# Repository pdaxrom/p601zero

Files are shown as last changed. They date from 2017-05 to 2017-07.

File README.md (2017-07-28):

## Pyldin-601 compatible retrocomputer.

[History](docs/HISTORY.md)

### Overview hardware version 1.2:

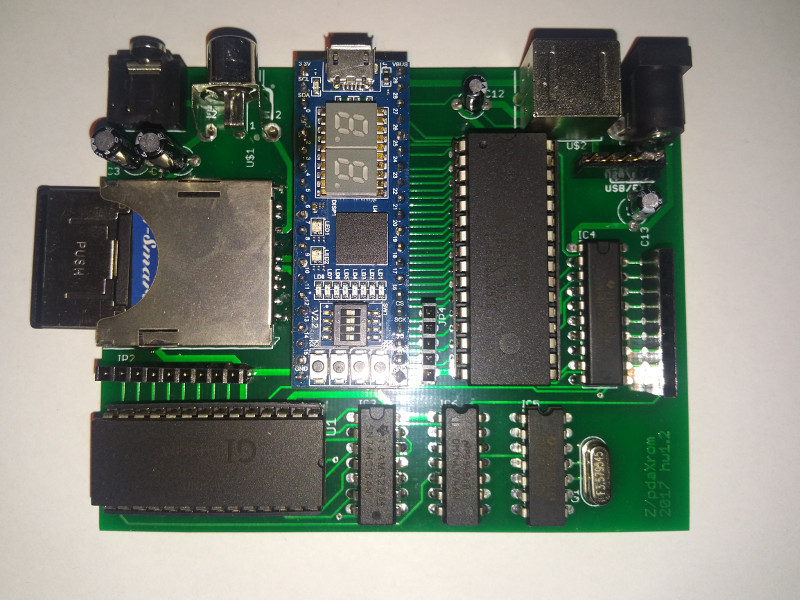
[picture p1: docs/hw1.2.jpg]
board version 1.2


 Function | Description 
----|----
CPU | [System 11 - VHDL 68HC11](http://members.optusnet.com.au/jekent/system11/)
FPGA| [Lattice MachXO2-4000HC module](http://www.stepfpga.com)
RAM | Builtin FPGA 4KB and/or external static ram 128KB
ROM | Builtin FPGA BOOTROM 2KB
Keyboard | PS/2
Serial port | UART (via keyboard connector)
Video | TV (b/w)
Audio | AY-3-8912
Storage | MMC/SD
Other | Onboard SPI and CS ports, 8 bit parallel port (limited to output only)

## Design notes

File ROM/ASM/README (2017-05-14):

Run compiled code on the board

1) Load code to the board
    ../bootloader /dev/ttyUSB0 load DEMO1.CMD 100

2) Run loaded code:
    ../bootloader /dev/ttyUSB0 go 100

For code that use UART, run terminal in non locking mode:
    picocom -l -b 115200 /dev/ttyUSB0

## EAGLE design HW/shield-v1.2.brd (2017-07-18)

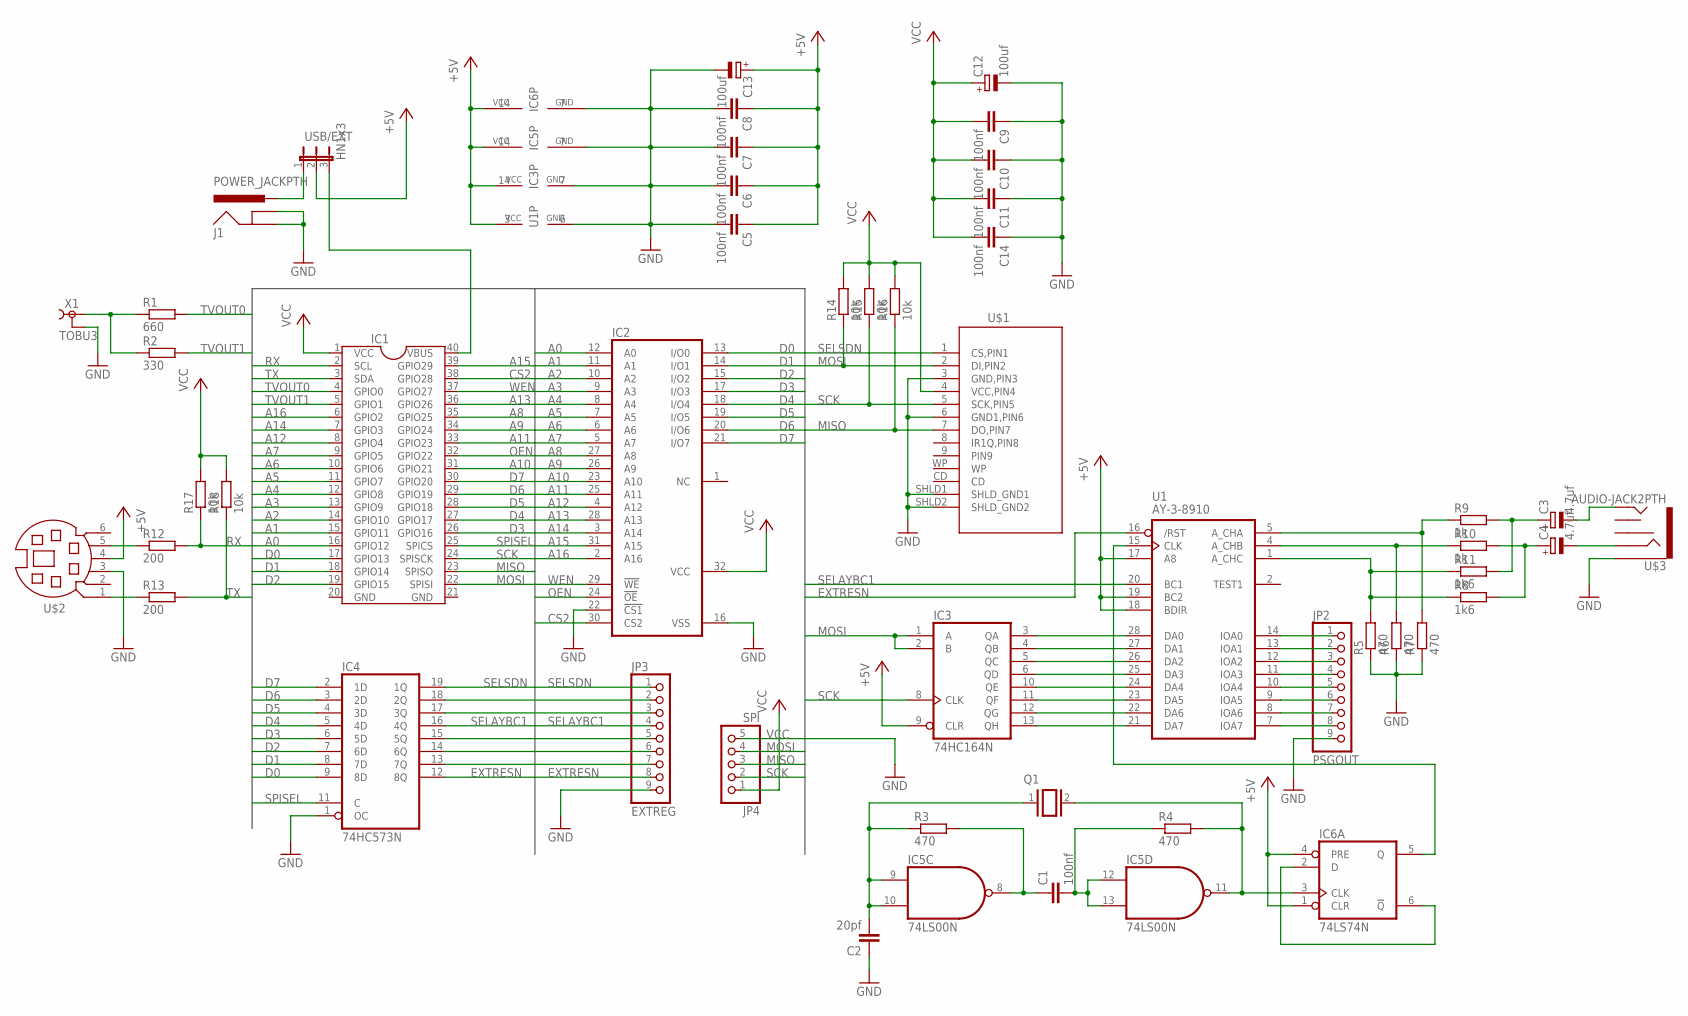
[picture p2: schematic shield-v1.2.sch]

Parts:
C1, C5, C6, C7, C8, C9, C10, C11, C14: 100nf; 1206
C2: 20pf; 1206
C3, C4: 4.7uf; E5-5
C12, C13: 100uf; E5-5
IC1: STEPFPGA; DIL40
IC2: 628128P; DIL32
IC3: 74HC164N; DIL14
IC4: 74HC573N; DIL20
IC5: 74LS00N; DIL14
IC6: 74LS74N; DIL14
J1: POWER_JACKPTH; POWER_JACK_PTH
JP2: PSGOUT; 1X09
JP3: EXTREG; 1X09
JP4: SPI; 1X05
Q1: XTAL/S; QS
R1: 660; R1206
R2: 330; R1206
R3, R4, R5, R6, R7: 470; R1206
R8, R11: 1k6; R1206
R9, R10: 1k; R1206
R12, R13: 200; R1206
R14, R15, R16, R17, R18: 10k; R1206
U1: AY-3-8910; DIL28-6
U$1: FCI_SD_SOCKET; SD-MMC_SOCKET-PP
U$2: MD06SS; MDIN06SS
U$3: AUDIO-JACK2PTH; AUDIO-JACK
USB/EXT: HN1x3; JP2
X1: TOBU3

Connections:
+5V: C5.1, C6.1, C7.1, C8.1, C13.+, IC3.9 (CLR), IC3.14 (VCC), IC5.14 (VCC), IC6.1 (CLR), IC6.4 (PRE), IC6.14 (VCC), U1.3 (VCC), U1.17 (A8), U1.18 (BDIR), U1.19 (BC2), U$2.4, USB/EXT.2
A0: IC1.16 (GPIO12), IC2.12 (A0)
A1: IC1.15 (GPIO11), IC2.11 (A1)
A2: IC1.14 (GPIO10), IC2.10 (A2)
A3: IC1.13 (GPIO9), IC2.9 (A3)
A4: IC1.12 (GPIO8), IC2.8 (A4)
A5: IC1.11 (GPIO7), IC2.7 (A5)
A6: IC1.10 (GPIO6), IC2.6 (A6)
A7: IC1.9 (GPIO5), IC2.5 (A7)
A8: IC1.35 (GPIO25), IC2.27 (A8)
A9: IC1.34 (GPIO24), IC2.26 (A9)
A10: IC1.31 (GPIO21), IC2.23 (A10)
A11: IC1.33 (GPIO23), IC2.25 (A11)
A12: IC1.8 (GPIO4), IC2.4 (A12)
A13: IC1.36 (GPIO26), IC2.28 (A13)
A14: IC1.7 (GPIO3), IC2.3 (A14)
A15: IC1.39 (GPIO29), IC2.31 (A15)
A16: IC1.6 (GPIO2), IC2.2 (A16)
CS2: IC1.38 (GPIO28), IC2.30 (CS2)
D0: IC1.17 (GPIO13), IC2.13 (I/O0), IC4.9 (8D)
D1: IC1.18 (GPIO14), IC2.14 (I/O1), IC4.8 (7D)
D2: IC1.19 (GPIO15), IC2.15 (I/O2), IC4.7 (6D)
D3: IC1.26 (GPIO16), IC2.17 (I/O3), IC4.6 (5D)
D4: IC1.27 (GPIO17), IC2.18 (I/O4), IC4.5 (4D)
D5: IC1.28 (GPIO18), IC2.19 (I/O5), IC4.4 (3D)
D6: IC1.29 (GPIO19), IC2.20 (I/O6), IC4.3 (2D)
D7: IC1.30 (GPIO20), IC2.21 (I/O7), IC4.2 (1D)
EXTRESN: IC4.12 (8Q), JP3.8, U1.16 (/RST)
GND: C2.1, C5.2, C6.2, C7.2, C8.2, C9.1, C10.1, C11.1, C12.-, C13.-, C14.1, IC1.20 (GND), IC1.21 (GND), IC2.16 (VSS), IC2.22 (!CS1), IC3.7 (GND), IC4.1 (OC), IC4.10 (GND), IC5.7 (GND), IC6.7 (GND), J1.GND, J1.GNDBREAK, JP2.9, JP3.9, JP4.5, R5.1, R6.1, R7.1, U1.6 (GND), U$1.3 (GND,PIN3), U$1.6 (GND1,PIN6), U$1.SHLD1 (SHLD_GND1), U$1.SHLD2 (SHLD_GND2), U$2.3, U$3.SLEEVE, X1.2, X1.2@1 (2), X1.2@2 (2)
MISO: IC1.23 (SPISO), JP4.3, R16.1, U$1.7 (DO,PIN7)
MOSI: IC1.22 (SPISI), IC3.1 (A), IC3.2 (B), JP4.4, R14.1, U$1.2 (DI,PIN2)
unnamed: R1.1, R2.1, X1.1
unnamed: IC3.3 (QA), U1.28 (DA0)
unnamed: IC3.4 (QB), U1.27 (DA1)
unnamed: IC3.5 (QC), U1.26 (DA2)
unnamed: IC3.6 (QD), U1.25 (DA3)
unnamed: IC3.10 (QE), U1.24 (DA4)
unnamed: IC3.11 (QF), U1.23 (DA5)
unnamed: IC3.12 (QG), U1.22 (DA6)
unnamed: IC3.13 (QH), U1.21 (DA7)
unnamed: R5.2, R8.1, R11.1, U1.1 (A_CHC)
unnamed: C1.1, IC5.8 (O), R3.2
unnamed: C1.2, IC5.12 (I0), IC5.13 (I1), R4.1
unnamed: C2.2, IC5.9 (I0), IC5.10 (I1), Q1.1, R3.1
unnamed: IC5.11 (O), IC6.3 (CLK), Q1.2, R4.2
unnamed: R6.2, R10.1, U1.4 (A_CHB)
unnamed: IC6.2 (D), IC6.6 (!Q)
unnamed: IC6.5 (Q), U1.15 (CLK)
unnamed: R7.2, R9.1, U1.5 (A_CHA)
unnamed: C4.+, R8.2, R10.2
unnamed: C3.+, R9.2, R11.2
unnamed: C3.-, U$3.TIP
unnamed: C4.-, U$3.RING
unnamed: R12.1, U$2.5
unnamed: R13.1, U$2.1
unnamed: JP2.1, U1.14 (IOA0)
unnamed: JP2.2, U1.13 (IOA1)
unnamed: JP2.3, U1.12 (IOA2)
unnamed: JP2.4, U1.11 (IOA3)
unnamed: JP2.5, U1.10 (IOA4)
unnamed: JP2.6, U1.9 (IOA5)
unnamed: JP2.7, U1.8 (IOA6)
unnamed: JP2.8, U1.7 (IOA7)
unnamed: IC4.18 (2Q), JP3.2
unnamed: IC4.17 (3Q), JP3.3
unnamed: IC4.15 (5Q), JP3.5
unnamed: IC4.14 (6Q), JP3.6
unnamed: IC4.13 (7Q), JP3.7
unnamed: J1.PWR, USB/EXT.1
unnamed: IC1.40 (VBUS), USB/EXT.3
OEN: IC1.32 (GPIO22), IC2.24 (!OE)
RX: IC1.2 (SCL), R12.2, R17.1
SCK: IC1.24 (SPISCK), IC3.8 (CLK), JP4.2, R15.1, U$1.5 (SCK,PIN5)
SELAYBC1: IC4.16 (4Q), JP3.4, U1.20 (BC1)
SELSDN: IC4.19 (1Q), JP3.1, U$1.1 (CS,PIN1)
SPISEL: IC1.25 (SPICS), IC4.11 (C)
TVOUT0: IC1.4 (GPIO0), R1.2
TVOUT1: IC1.5 (GPIO1), R2.2
TX: IC1.3 (SDA), R13.2, R18.1
VCC: C9.2, C10.2, C11.2, C12.+, C14.2, IC1.1 (VCC), IC2.32 (VCC), IC4.20 (VCC), JP4.1, R14.2, R15.2, R16.2, R17.2, R18.2, U$1.4 (VCC,PIN4)
WEN: IC1.37 (GPIO27), IC2.29 (!WE)

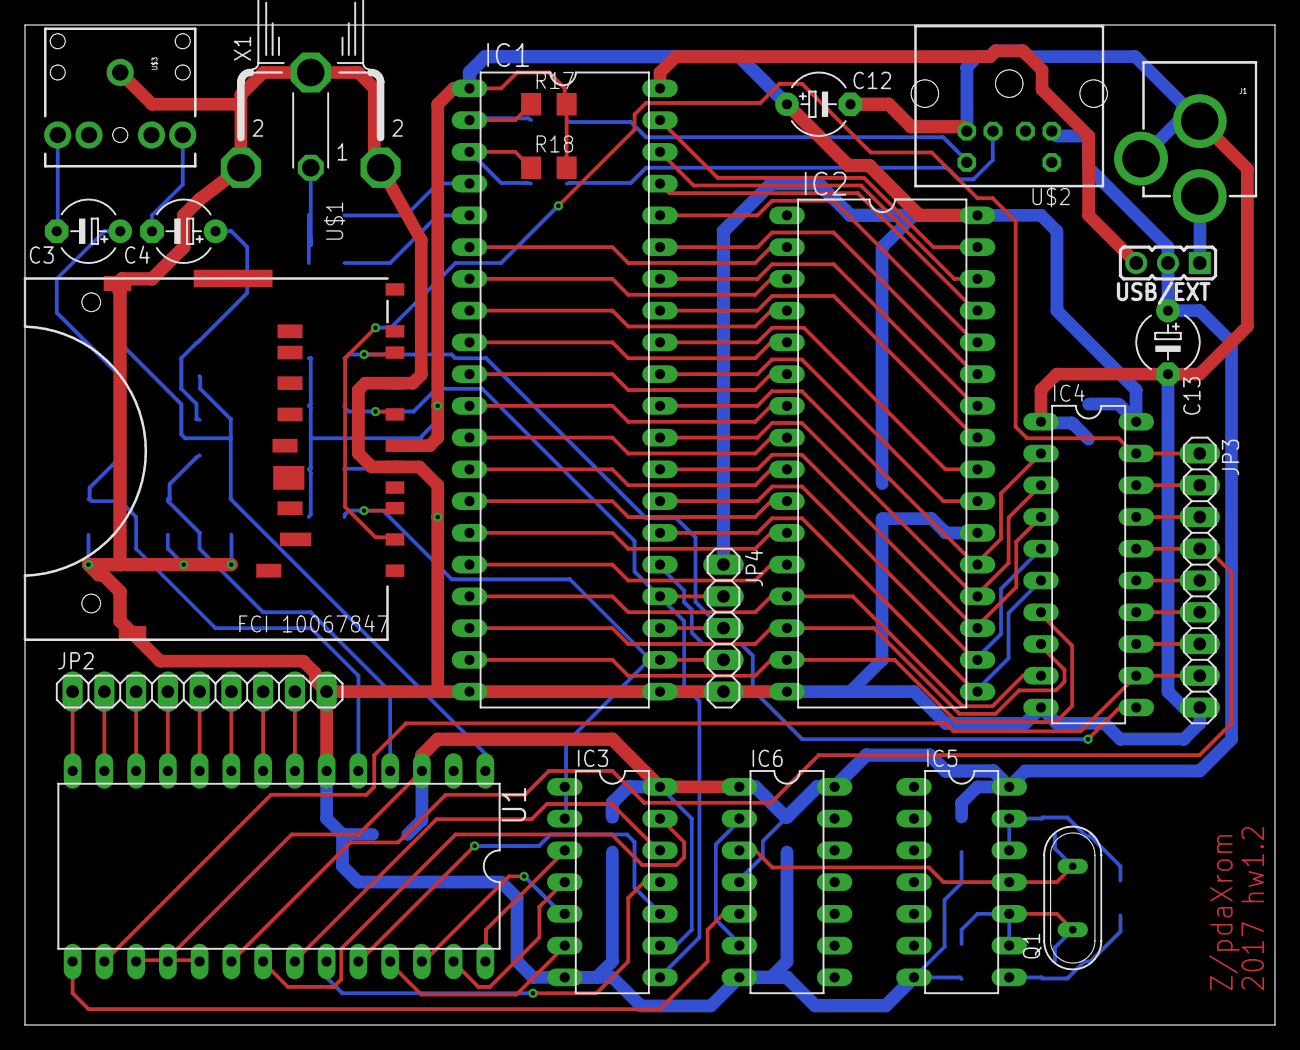
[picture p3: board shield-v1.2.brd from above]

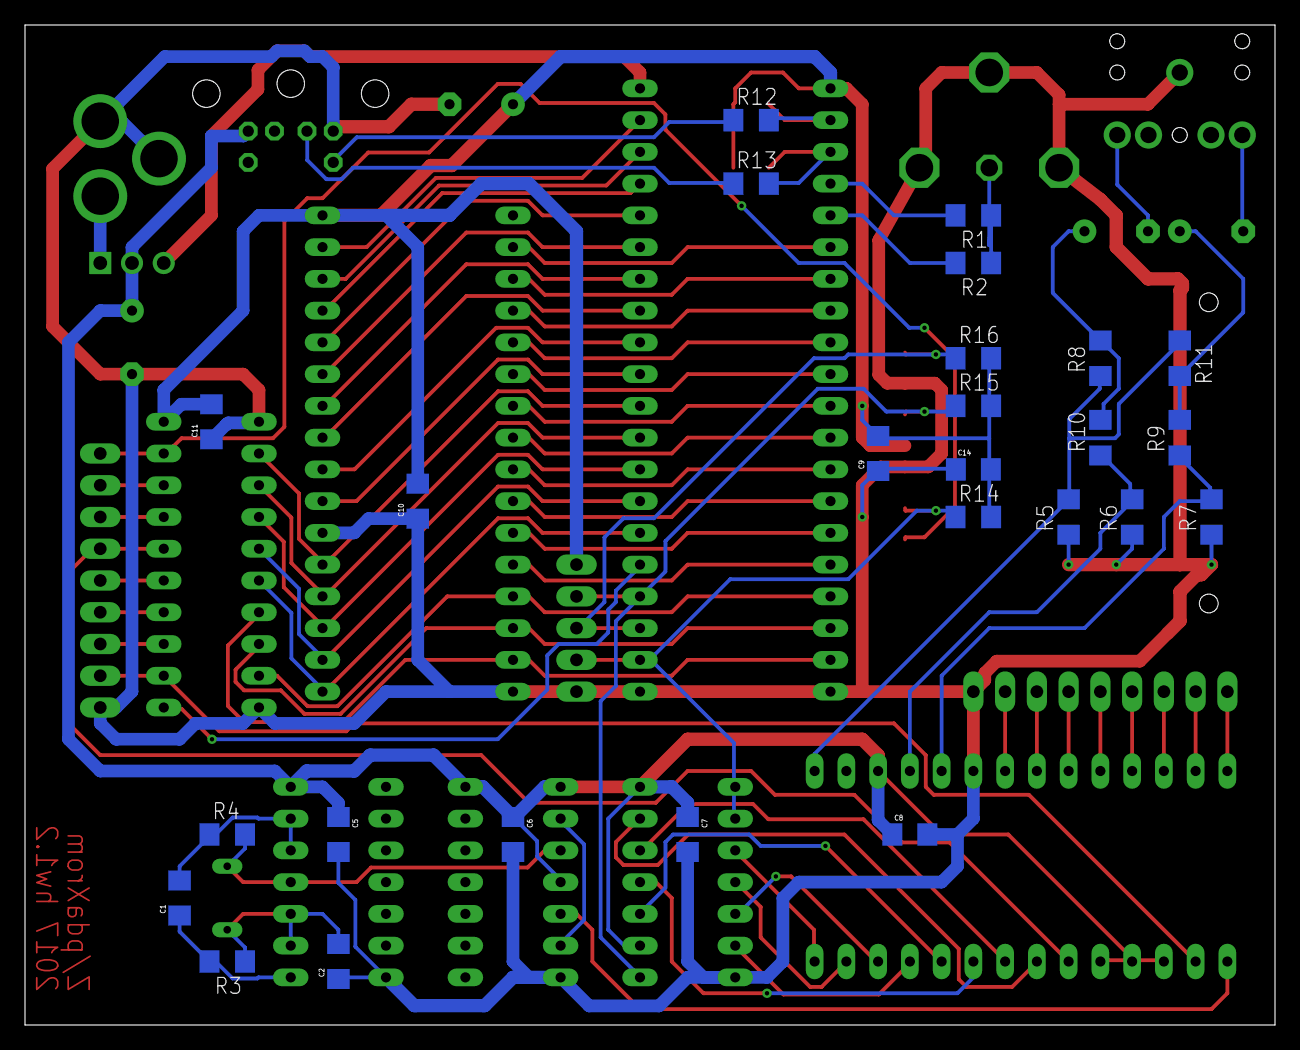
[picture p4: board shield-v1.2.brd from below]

Board: 2 copper layers, 100.0 x 80.0 mm, 49 parts (26 on the bottom side), 81 nets.

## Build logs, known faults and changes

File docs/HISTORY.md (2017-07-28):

# History of pdaXrom

year | description
-----|-----
2003-2007 | arm linux distro for Sharp Zaurus PDA.
2007-2014 | renamed as pdaXrom-ng, powerpc bootloader and distro for Sony Playstation 3, mips32/64 distro for Lemote Yeeloong 8101B, arm distro for RAME/PCIO terminal hardware
2012-2017 | cctools - development packages for Android
2017 | Z/pdaXrom - FPGA based computer

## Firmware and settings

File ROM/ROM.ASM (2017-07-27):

;
; BOOTROM for Z/pdaXrom
; (c) sashz <sashz@pdaXrom.org>, 2017
;

	include DEVMAP.INC

;
; BootROM variables and functions
;

	include BOOTROM.INC

	include BOOTMEM.INC

	org	BOOTROM_BASE

reset	sei

	ldaa	RAMPAGE_CTL
	oraa	#BRAM_DISABLE
	staa	RAMPAGE_CTL

; SRAM chip initialization
	ldaa	#0
sramini	ldx	#$A55A
	stx	$0
	ldx	$0
	cpx	#$A55A
	bne	sramin1
	ldab	IO_SWKEYS
	bitb	#1
	beq	sramok
	bra	onbrom
sramin1	inca
	bne	sramini

onbrom	ldab	RAMPAGE_CTL
	andb	#($FF^BRAM_DISABLE)
	stab	RAMPAGE_CTL
	ldab	#$1C
	stab	IO_L7HI
sramok	staa	$2
	staa	IO_L8BIT

; setup stubs
	ldx	#0
	stx	VECIRQP
	stx	VECNMIP

	ldx	#vstub_irq
	stx	VECIRQ
	ldx	#vstub_nmi
	stx	VECNMI
	ldx	#swihndl
	stx	VECSWI

; setup syscalls

	ldx	#BROM_SWIPAG
clrswipag clr	0,x
	inx
	cpx	#BROM_SWIPAG+$280
	bne	clrswipag

	lds	#romvecbeg
	des
	ldx	#BROM_SWIVEC+$C0*2
copyswiv pula
	staa	0,x
	inx
	cpx	#BROM_SWIVEC+$C0*2+(romvecend-romvecbeg)
	bne	copyswiv

	ldaa	IO_SWKEYS
	bita	#$80
	bne	setuart
	ldaa	#PS2_KEN
	bra	setkbd
setuart	clra
setkbd	staa	PS2_CONFIG

warmres	lds	#BROM_STACK

; reset spi/EXT devices
	jsr	spi_reset

; init putchar queue for control sequences
	clr	QUEUELEN
	ldx	#QUEUEBUF
	stx	QUEUEPTR

	ldaa	#$80
	ldx	#FBTEXT
	jsr	setvideomode

; setup prescaler: 24MHz / (Baud * 8)
	ldx	#26
	stx	UART_PRESCALER

; disable UART interrupts (clear UART_TIE and UART_RIE)
	clra
	staa	UART_CONFIG

	ldx	#pylogo
	jsr	putstr

	ldaa	RAMPAGE_CTL
	bita	#BRAM_DISABLE
	beq	bramen
	ldx	#txt_extram
	bra	ramtxt
bramen	ldx	#txt_bram
ramtxt	jsr	putstr

	ldaa	PS2_CONFIG
	bita	#PS2_KEN
	beq	showuart
	ldx	#txt_kbd
	bra	showkbd
showuart ldx	#txt_uart
showkbd	jsr	putstr

;
; Trying to boot from SD
;
	jsr	sd_init
	tsta
	bne	no_sd_boot
	ldx	#txt_sd
	jsr	putstr

	ldx	#boot_sec
	jsr	sd_read
	tsta
	bne	no_sd_boot
	ldx	$2FE
	cpx	#$55AA
	bne	no_sd_boot
	jsr	$13E

no_sd_boot ldx	#txt_nl
	jsr	putstr

loop	bsr	uart_in
	cmpa	#'L'
	beq	cmd_load
	cmpa	#'S'
	beq	cmd_save
	cmpa	#'G'
	beq	cmd_go
	ldaa	#'E'
	bsr	uart_out
	bra	loop

cmd_load
	bsr	get_block_addr
cmd_lo1	bsr	uart_in
	staa	0,x
	inx
	cpx	END_ADDR
	bne	cmd_lo1
cmd_oka	ldaa	#'O'
	bsr	uart_out
	bra	loop

cmd_save
	bsr	get_block_addr
cmd_sa1	ldaa	0,x
	bsr	uart_out
	inx
	cpx	END_ADDR
	bne	cmd_sa1
	bra	cmd_oka

cmd_go
	bsr	get_word
	jsr	0,x
	jmp	warmres

get_block_addr proc
	bsr	get_word
	pshx
	bsr	get_word
	stx	END_ADDR
	pulx
	rts
	endp

;; UART IN/OUT

uart_in proc
	ldaa	UART_STATUS
	bita	#UART_RRD
	beq	uart_in
	ldaa	UART_DATA
	rts
	endp

uart_out proc
	pshb
loop	ldab	UART_STATUS
	bitb	#UART_TRD
	beq	loop
	staa	UART_DATA
	pulb
	rts
	endp

get_word proc
	bsr	uart_in
	tab
	bsr	uart_in
	psha
	pshb
	pulx
	rts
	endp

;;;;;;;;;;;;;;;;;;;;;;;;;;;;;;;;;;;;;;;;;;;;;;;;;;;;;;;;;;;;;;;;;;;;;;;;;;;;;;;;
;;;;;;;;;;;;;;;;;;;;;;;;;;;;;;;;;;;;;;;;;;;;;;;;;;;;;;;;;;;;;;;;;;;;;;;;;;;;;;;;
;;;;;;;;;;;;;;;;;;;;;;;;;;;;;;;;;;;;;;;;;;;;;;;;;;;;;;;;;;;;;;;;;;;;;;;;;;;;;;;;
; Get PS/2 keyboard code
; Return A - code
;
;getscancode proc
;loop	ldaa	PS2_STATUS
;	bita	#PS2_KRD
;	beq	loop
;	ldaa	PS2_DATA
;	rts
;	endp

;;;;;;;;;;;;;;;;;;;;;;;;;;;;;;;;;;;;;;;;;;;;;;;;;;;;;;;;;;;;;;;;;;;;;;;;;;;;;;;;
;;;;;;;;;;;;;;;;;;;;;;;;;;;;;;;;;;;;;;;;;;;;;;;;;;;;;;;;;;;;;;;;;;;;;;;;;;;;;;;;
;;;;;;;;;;;;;;;;;;;;;;;;;;;;;;;;;;;;;;;;;;;;;;;;;;;;;;;;;;;;;;;;;;;;;;;;;;;;;;;;
; Set video mode
; A = $00 - text, $03 - graphics,
; X = Video address
;

setvideomode proc
	pshx
	pshb
	psha
	stx	SCRADDR
	stab	SCRATTR
	tab
	anda	#$7F
	staa	SCRMODE
	ldx	txtmode
	stx	SCRSZX
	ldx	txtmode+2
	stx	SCRXADJ
	ldx	txtmode+4
	stx	SCRMASK
	cmpa	#0
	bne	mode3
	inc	SCRSZY		; 27 text rows
	inc	SCRSZY		;
	bitb	#$80
	beq	next
	ldaa	SCRSZY
	bra	clrs
mode3	cmpa	#3
	bne	exit
	ldaa	#VPU_GRF
	staa	SCRBITS
	bitb	#$80
	beq	next
	ldaa	SCRSZY
	lsla
	lsla
	lsla
clrs	jsr	clrscry
	clr	CURX
	clr	CURY
next	ldx	#SCRADDR
	bsr	vpuconfig
	ldaa	CURX
	ldaa	CURY
	bsr	setcursor
exit	pula
	pulb
	pulx
	rts

txtmode	db	40, 25, 11, 60, $FF^VPU_GRF, 0
	endp

; Configure VPU
; X = ptr
;
; ptr dw vaddr  ; 0
;     db width  ; 2
;     db height ; 3
;     db hadj   ; 4
;     db vadj   ; 5
;     db mask   ; 6
;     db bits   ; 7
;

vpuconfig proc
	pshb
	psha

; Set framebuffer address
	ldd	0,x
	std	VPU_VADDR

; Set start line
	clra
	ldab	5,x
	std	VPU_VSTART

; Set end line
	clra
	ldab	3,x
	lsld
	lsld
	lsld
	addd	VPU_VSTART
	std	VPU_VEND

; Framebuffer horisontal position
	ldaa	4,x
	staa	VPU_HSTART

; Start dma engine
	ldaa	2,x
	staa	VPU_HSIZE

; Set bits
	ldaa	#VPU_GRF
	anda	6,x
	oraa	7,x
	staa	VPU_CFG

	pula
	pulb
	rts
	endp

; Get video mode
; Return
; X - address
; A - mode
; B - attributes

getvideomode proc
	ldaa	SCRMODE
	ldab	SCRATTR
	ldx	SCRADDR
	rts
	endp

;;;;;;;;;;;;;;;;;;;;;;;;;;;;;;;;;;;;;;;;;;;;;;;;;;;;;;;;;;;;;;;;;;;;;;;;;;;;;;;;
;;;;;;;;;;;;;;;;;;;;;;;;;;;;;;;;;;;;;;;;;;;;;;;;;;;;;;;;;;;;;;;;;;;;;;;;;;;;;;;;
;;;;;;;;;;;;;;;;;;;;;;;;;;;;;;;;;;;;;;;;;;;;;;;;;;;;;;;;;;;;;;;;;;;;;;;;;;;;;;;;
; Set VPU cursor
; A - column
; B - row
;

vpucursor proc
	pshx
	pshb
	psha
	adda	#11
	inca
	staa	VPU_CPOS
	clra
	lsld
	lsld
	lsld
	ldx	#60
	pshx
	tsx
	addd	0,x
	pulx
	std	VPU_CSTART
	addd	#7
	std	VPU_CEND

	ldaa	VPU_CFG
	oraa	#VPU_CEN
	oraa	#VPU_CIN
;	anda	#($FF ^ VPU_CIN)
	staa	VPU_CFG

	pula
	pulb
	pulx
	rts
	endp

setcursor proc
	cmpa	SCRSZX
	bcc	exit
	cmpb	SCRSZY
	bcc	exit
	pshb
	psha
	staa	CURX
	stab	CURY
	bsr	vpucursor
	ldaa	SCRSZX
	mul
	std	CURPTR
	clra
	ldab	CURX
	addd	CURPTR
	addd	SCRADDR
	std	CURPTR
	pula
	pulb
exit	rts
	endp

getcursor proc
	ldaa	CURX
	ldab	CURY
	ldx	CURPTR
	rts
	endp

putchar	proc
	pshx
	pshb
	psha
	ldab	PS2_CONFIG
	bitb	#PS2_KEN
	bne	nouart
	jsr	uart_out

nouart	ldab	SCRMODE
	andb	#$03
	bne	return1		; graf mode not supported

	tst	QUEUELEN
	beq	putch0
queue1	ldx	QUEUEPTR
	staa	0,x
	inx
	stx	QUEUEPTR
	dec	QUEUELEN
	bne	return1
	ldx	#QUEUEBUF
	stx	QUEUEPTR
	ldaa	0,x
	cmpa	#$1E
	bne	queue1b
	ldaa	1,x
	suba	#$20
	ldab	2,x
	subb	#$20
	bsr	setcursor
	bra	return1
queue1b	cmpa	#$1B
	bne	return1
	ldaa	1,x
	bra	putnorm

return1	pula
	pulb
	pulx
	rts

putch0	cmpa	#$1B
	bne	putc1e
	ldab	#2
queueup	stab	QUEUELEN
	bra	queue1
putc1e	cmpa	#$1E
	bne	putc08
	ldab	#3
	bra	queueup
putc08	cmpa	#$08
	bne	putc09
	ldaa	CURX
	deca
	ldab	CURY
	bra	setcur
putc09	cmpa	#$09
	bne	putc0a
	ldaa	CURX
	adda	#8
	anda	#%11111000
	ldab	CURY
	bra	setcur
putc0a	cmpa	#$0A
	bne	putch0c
	ldaa	CURX
	ldab	CURY
	incb
	cmpb	SCRSZY
	bne	setcur
	bsr	scroll
	bra	return1
putch0c	cmpa	#$0C
	bne	putch0d
	bsr	clrscr
	clra
	clrb
	bra	setcur
putch0d	cmpa	#$0D
	bne	putch18
	clra
	ldab	CURY
	bra	setcur
putch18	cmpa	#$18
	bne	putch7f
	bsr	clr2eol
	bra	return1
putch7f	cmpa	#$7F
	bne	putnorm
	ldaa	CURX
	beq	return1
	deca
	ldx	CURPTR
	dex
	clr	0,x
	ldab	CURY
	bra	setcur
putnorm	ldx	CURPTR
	staa	0,x
	ldaa	CURX
	ldab	CURY
	inca
setcur	jsr	setcursor
	jmp	return1
	endp

clrscr	proc
	global	clrscry, clr2eol
	ldaa	SCRSZY
clrscry	ldab	SCRSZX
	mul
	ldx	SCRADDR
clrs1	clr	0,x
	inx
	subd	#1
	bne	clrs1
	rts

clr2eol	ldx	CURPTR
	ldaa	SCRSZY
	suba	CURX
eoloop	clr	0,x
	inx
	deca
	bne	eoloop
	rts
	endp
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

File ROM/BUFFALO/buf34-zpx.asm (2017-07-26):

*                  BUFFALO
* "Bit User's Fast Friendly Aid to Logical Operation"
*
* Rev 2.0 - 4/23/85 - added disassembler.
*                   - variables now PTRn and TMPn.
* Rev 2.1 - 4/29/85 - added byte erase to chgbyt routine.
* Rev 2.2 - 5/16/85 - added hooks for evb board - acia
*                     drivers, init and host routines.
*           7/8/85  - fixed dump wraparound problem.
*           7/10/85 - added evm board commands.
*                   - added fill instruction.
*           7/18/85 - added jump to EEPROM.
* Rev 2.3 - 8/22/85 - call targco to disconnect sci from host
*                     in reset routine for evb board.
*           10/3/85 - modified load for download through terminal.
* Rev 2.4 - 7/1/86  - Changed DFLOP address to fix conflicts with
*                     EEPROM.  (was at A000)
* Rev 2.5 - 9/8/86  - Modified to provide additional protection from
*                     program run-away on power down.  Also fixed bugs
*                     in MM and MOVE.  Changed to 1 stop bit from 2.
* Rev 2.6 - 9/25/86 - Modified boot routine for variable length download
*                     for use with 'HC11E8.
* Rev 3.0   1/15/87 - EEPROM programming routines consolidated into WRITE.
*                     Fill, Assem, and breakpoints will now do EEPROM.
*                   - Added compare a to $0D to WSKIP routine.
*           2/11/87 - Set up load to detect receiver error.
* Rev 3.2   7/7/87  - Add disassembly to trace.
*                   - Add entries to jump table.
*           9/20/87 - Rewrote trace to use XIRQ, added STOPAT Command
*           11/24/87- Write block protect reg for 'E9 version
*                   - Modified variable length download for use
*                       with 'E9 bootloader (XBOOT command)
* Rev 3.3   3/17/88 - Set I bit to block interrupts on Warm Start and 
*                       return from CALL command.
*                   - Added EEMOD Command.
*                   - Rearranged source so that HELP command overlaps
*                       EEPROM in test mode.
*           3/24/88 - Added '+', '-', '=', '.' to MEM and ASM commands.
*                   - Added check for 16 byte boundary to MEM 
*                       space sub-command.
*                   - LOAD command now puts dummy (~) command into
*                       inbuff so that any stray cr's won`t hang.
* Rev 3.4   8/15/88 - Changed WRITE subroutine so that config register 
*                       gets byte erased before programmed.  The original
*                       value of config is used for EEBYTE so that config
*                       RAM value doesn't get changed in test mode.
*           8/17/88 - Fixed MOVE command so that it doesn't hang when move
*                       is done to a ROM location.
*                   - Added OFFSET command for download offset capability.
*
****************************************************
*    Although the information contained herein,    *
*    as well as any information provided relative  *
*    thereto, has been carefully reviewed and is   *
*    believed accurate, Motorola assumes no        *
*    liability arising out of its application or   *
*    use, neither does it convey any license under *
*    its patent rights nor the rights of others.   *
****************************************************

; UART module

UART_DATA	equ	$E6B0
UART_CONFIG	equ	$E6B1
UART_STATUS	equ	$E6B1
UART_PRESCALER	equ	$E6B2

UART_RRD	equ	$1
UART_ROE	equ	$2
UART_RFE	equ	$4
UART_TRD	equ	$8
UART_RIE	equ	$10
UART_TIE	equ	$20
UART_RIQ	equ	$40
UART_TIQ	equ	$80

***************
*   EQUATES   *
***************
*Author EQU  Tony Fourcroy
RAMBS   EQU  $0000      start of ram
;REGBS   EQU  $1000      start of registers
ROMBS   EQU  $C000      start of rom
;DSTREE  EQU  $B600      start of eeprom
;DENDEE  EQU  $B7FF      end of eeprom
;PORTE   EQU  REGBS+$0A  port e
;CFORC   EQU  REGBS+$0B  force output compare
;TCNT    EQU  REGBS+$0E  timer count
;TOC5    EQU  REGBS+$1E  oc5 reg
;TCTL1   EQU  REGBS+$20  timer control 1
;TMSK1   EQU  REGBS+$22  timer mask 1
;TFLG1   EQU  REGBS+$23  timer flag 1
;TMSK2   EQU  REGBS+$24  timer mask 2
;BAUD    EQU  REGBS+$2B  sci baud reg
;SCCR1   EQU  REGBS+$2C  sci control1 reg
;SCCR2   EQU  REGBS+$2D  sci control2 reg
;SCSR    EQU  REGBS+$2E  sci status reg
;SCDAT   EQU  REGBS+$2F  sci data reg
;BPROT   EQU  REGBS+$35  block protect reg
;OPTION  EQU  REGBS+$39  option reg
;COPRST  EQU  REGBS+$3A  cop reset reg
;PPROG   EQU  REGBS+$3B  ee prog reg
;HPRIO   EQU  REGBS+$3C  hprio reg
;CONFIG  EQU  REGBS+$3F  config register
;DFLOP   EQU  $4000      evb d flip flop
;DUART   EQU  $D000      duart address
;PORTA   EQU  DUART
;PORTB   EQU  DUART+8
;ACIA    EQU  $9800      acia address
PROMPT  EQU  '>'
BUFFLNG EQU  35
CTLA    EQU  $01        exit host or assembler
CTLB    EQU  $02        send break to host
CTLW    EQU  $17        wait
CTLX    EQU  $18        abort
DEL     EQU  $7F        abort
EOT     EQU  $04        end of text/table
SWI     EQU  $3F

***************
*     RAM     *
***************
        ORG  $2D
*** Buffalo ram space ***
        RMB  20    user stack area
USTACK  RMB  30    monitor stack area
STACK   RMB  1
REGS    RMB  9     user's pc,y,x,a,b,c
SP      RMB  2     user's sp
INBUFF  RMB  BUFFLNG    input buffer
ENDBUFF EQU  *
COMBUFF RMB  8     command buffer
SHFTREG RMB  2     input shift register
STREE   RMB  2     eeprom start address
ENDEE   RMB  2     eeprom end address
BRKTABL RMB  8     breakpoint table
AUTOLF  RMB  1     auto lf flag for i/o
IODEV   RMB  1     0=sci,  1=acia, 2=duartA, 3=duartB
EXTDEV  RMB  1     0=none, 1=acia, 2=duart,
HOSTDEV RMB  1     0=sci,  1=acia,           3=duartB
COUNT   RMB  1     # characters read
CHRCNT  RMB  1     # characters output on current line
PTRMEM  RMB  2     current memory location
LDOFFST RMB  2     offset for download

*** Buffalo variables - used by: ***
PTR0    RMB  2     main,readbuff,incbuff,AS
PTR1    RMB  2     main,BR,DU,MO,AS,EX
PTR2    RMB  2     EX,DU,MO,AS
PTR3    RMB  2     EX,HO,MO,AS
PTR4    RMB  2     EX,AS
PTR5    RMB  2     EX,AS,BOOT
PTR6    RMB  2     EX,AS,BOOT
PTR7    RMB  2     EX,AS
PTR8    RMB  2     AS
TMP1    RMB  1     main,hexbin,buffarg,termarg
TMP2    RMB  1     GO,HO,AS,LOAD
TMP3    RMB  1     AS,LOAD
TMP4    RMB  1     TR,HO,ME,AS,LOAD
*** Vector jump table ***
JSCI    RMB   3
JSPI    RMB   3
JPAIE   RMB   3
JPAO    RMB   3
JTOF    RMB   3
JTOC5   RMB   3
JTOC4   RMB   3
JTOC3   RMB   3
JTOC2   RMB   3
JTOC1   RMB   3
JTIC3   RMB   3
JTIC2   RMB   3
JTIC1   RMB   3
JRTI    RMB   3
JIRQ    RMB   3
JXIRQ   RMB   3
JSWI    RMB   3
JILLOP  RMB   3
JCOP    RMB   3
JCLM    RMB   3

*****************
*
* ROM starts here *
*
*****************

        ORG  ROMBS

	fdb	$A55A
	fcc	'BUFFALO '
	jmp	p601_init
	jmp	p601_monitor
	fcb	0		; No Pyldin 601 swi calls here
p601_init	rts
p601_monitor	rts
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

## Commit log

2017-04-16 uart initial
2017-05-06 rx uart module
2017-05-06 RX error added to status register
    [ROM.ASM]
2017-05-06 tx uart implementation
2017-05-06 added missed VMA signal
    [ROM.ASM]
2017-05-06 fix uart
2017-05-07 added programmable timer to simpleio, irq. uart removed from simpleio to separate module
2017-05-11 working uart rx/tx
2017-05-12 device map include file
2017-05-12 uartio rx/tx interrupt support initial
2017-05-12 uart interrupts
2017-05-12 fixed warnings and interrupt flags
2017-05-12 set default uart speed to 115200
2017-05-14 UART DEMO, MICROBASIC
2017-05-14 fixed chars printed to terminal
    [MICROBASIC.ASM]
2017-05-15 MicroBasicPlus sources fixed for 6803 asm
    [MICROBASICPLUS.ASM]
2017-05-18 fix ext clock to 24MHz
    [BOOTROM.ASM, DEMO2.ASM, ROM.ASM]
2017-05-19 reworked for prototype board version 1
2017-05-20 working linear framebuffer
2017-05-22 page selector, linear framebuffer
2017-05-22 fixed framebuffer
2017-05-30 fixed sram OEn and WEn
    [MICROBASIC.ASM, ROM.ASM]
2017-05-30 simpleio timer clock is clk_in (24MHz)
2017-06-02 vpu dma demo
2017-06-02 dma engine
2017-06-02 at least 3 nops must be after start the VPU DMA engine
2017-06-02 fix DMA start code
2017-06-02 nmi as video interrupt
2017-06-02 video driver for linear framebuffer
2017-06-03 removed CPU register access to vpu line buffer, each dma transfer reset destination buffer address to VPU_ADDR value
2017-06-04 interrupt vectors registers added to page selector device, ext/int ram detection added to BOOTROM
2017-06-05 spi select external register
2017-06-06 spi reset sygnal added
    [PSGDEMO.ASM]
2017-06-08 ram wait cycles for VPU DMA engine
2017-06-17 updated assembler, linker and library added
2017-06-17 export C headers for devices and bootrom
2017-06-17 C samples
2017-06-19 fix regnames, remove old sources
    [PSGDEMO.ASM]
2017-06-19 VPU fixed, BOOTROM updated
    [ROM.ASM]
2017-06-19 autoincrement char line counter on each vpu interrupt
2017-06-20 hw dma access to video buffer, text and graphics modes
2017-06-23 count sram reset cycles
    [ROM.ASM]
2017-06-23 SD card IO fixed in ROM
    [ROM.ASM, SDSECRW.ASM]
2017-07-09 board revision 1.1
    [DRILEGEND.CFG, shield-v1.1.brd, shield-v1.1.sch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]
2017-07-11 Moved to 6811 core. Because CPX now use full flags for comparison, some old 6800 applications can work wrong
    [MICROBASIC.ASM, ROM.ASM]
2017-07-18 hw 1.2 - final for current schematic
    [shield-v1.2.brd, shield-v1.2.sch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]
2017-07-26 SW4 UART/Keyboard port switch

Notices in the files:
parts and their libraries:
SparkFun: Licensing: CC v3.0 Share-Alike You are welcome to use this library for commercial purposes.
